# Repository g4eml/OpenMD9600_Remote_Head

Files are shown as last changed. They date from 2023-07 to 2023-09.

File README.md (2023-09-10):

# OpenMD9600_Remote_Head

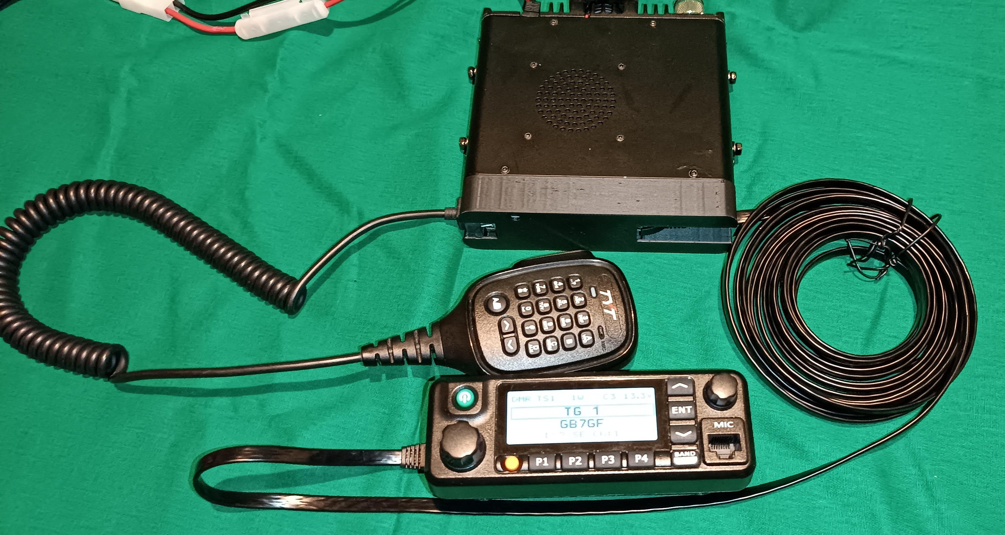
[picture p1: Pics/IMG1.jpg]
MD9600 Remote Head
 

The MD9600 is a good DMR mobile radio but, as standard, it does not have the ability to mount the control head remotely to the main body of the radio. 

The Control Head of the radio is normally connected to the front panel by a 30 conductor Flat Flexible cable. It is impractical to try to extend this cable. 

Now that the radio is able to run the excellent OpenMD9600 firmware it became possible to develop a way of communicating between the radio and the front panel using only a single RJ45 Cat7 cable. This currently requires a modified version of the OpenMD9600 firmware (available from G4EML) but it is hoped that this will be included in a future release of the firmware.  

### <mark>**Note that this modification will only work with the OpenMD9600 firmware. It will not work with the original TYT factory firmware.**</mark>

The mod requres two new small PCBs. 

### Radio Body Interface PCB

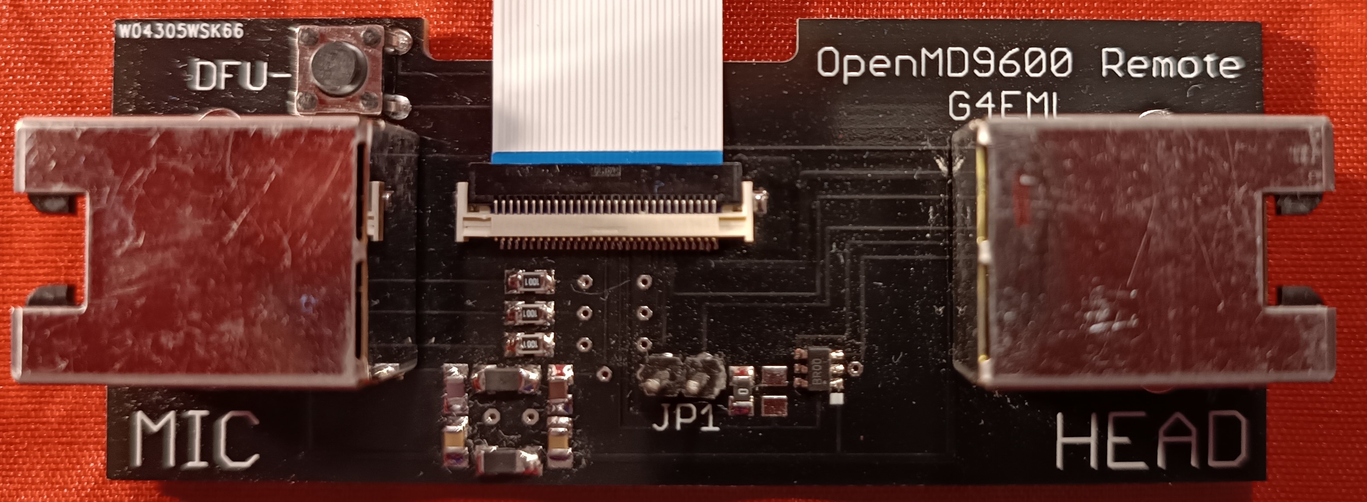
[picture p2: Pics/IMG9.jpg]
BodyPCB


This PCB is fitted to the front of the radio body and is connected to the existing 30 way ribbon cable. The necessary signals are routed to a RJ45 socket. A second RJ45 socket is also provided for direct connection of the microphone to the radio body.  Whilst the microphone can still be connected to the remotely mounted head this can suffer from pickup of noise due to the poor screening of the RJ45 cable. It is therefore recommended to connect the microphone directly to the radio body, using an extension cable if necessary. 

The modifed OpenMD9600 firmware detects the presence of the interface board and reconfigures the existing signals into a suitable format. This is a bi-directional 250000 Baud serial link.  Using this link display data is sent to the remote head PCB and front panel key presses are received from it. 

The PCB includes a digital potentiometer chip which is used to control the radio volume.  This chip is controlled by the remote head PCB.  This is necessary to reduce audio noise pickup on the long cable. Also fitted is a power switch chip which is used to control the power to the microphone. 

### Remote Head Interface PCB

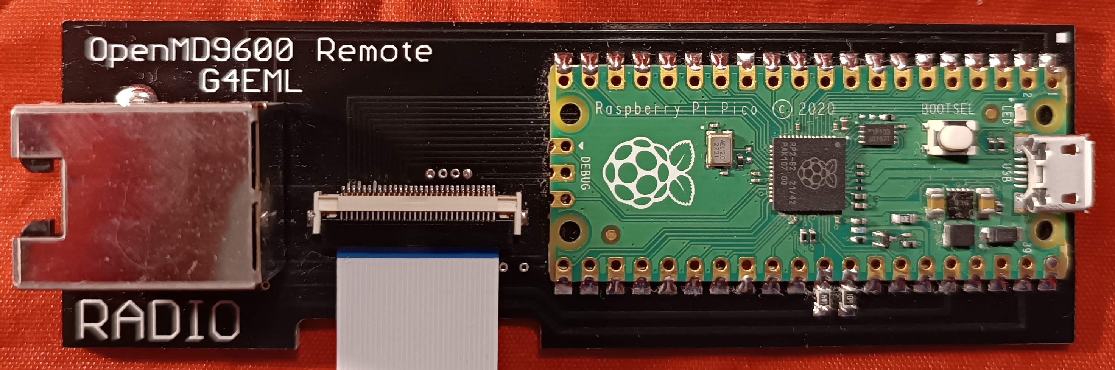
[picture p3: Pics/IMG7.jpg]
Head


This PCB is fitted to the rear of the remote head and connects to the existing 30 way connector.  Serial data to and from the radio body is handled by a Raspberry Pi Pico module which decodes the data and sends it to the Front Panel display, it also reads the front panel buttons and sends their staus to the radio body. 

### Installation

To convert a MD9600 to remote head operation requires the following steps. 

1. Remove front panel from the radio and disconnect the 30 way ribbon cable from the main body. Leave this cable connected to the head.

2. Fit a new 30 way cable between the radio body and the radio body Interface PCB. 

3. Attach the PCB to the front of the radio body using double sided foam tape. 

4. Connect the existing front panel 30 way cable to the remote head interface PCB. 

5. Attach the PCB to the rear of the front panel using double sided foam tape. 

6. Connect the two PCBs togetehr with the RJ45 cable. 

7. Connect the microphone to the second socket on the radio body PCB. 

8. Ensure the MD9600 is running the correct version of OpenMD9600.

9. Power on the radio. It should behave exactly as it did before. 

10. The files are also provided to 3D print covers for the radio body and the head. These are optional but do provide additional protection for the PCBs. 

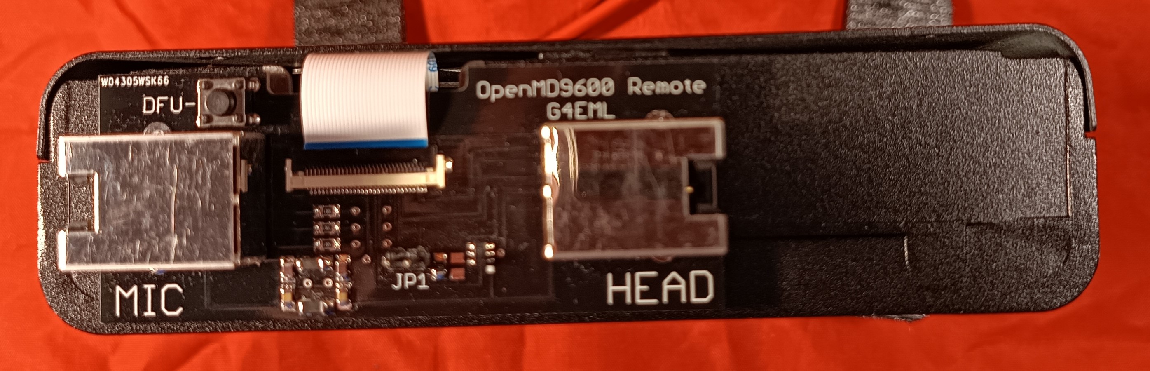
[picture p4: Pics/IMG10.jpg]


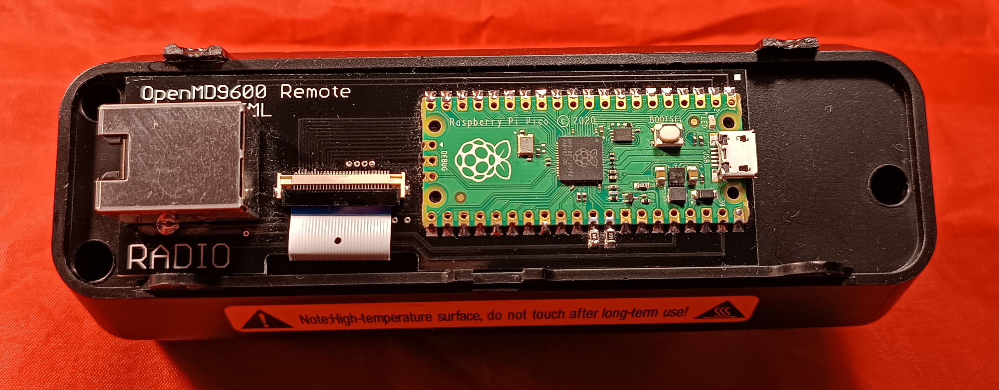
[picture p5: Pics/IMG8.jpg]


### How do I make these boards?

All of the information needed to make your own boards is included in this repository. The gerber files for the PCBs are provided and it is now very easy and cheap to get PCBs made in China. Companies such as PCBWAY will accept the Zipped Gerber files as provided and produce 10 PCBs for about £5.  so that is £10 for 10 of both PCBs. I would suggest that you get together with other people in your country and order the boards. 

The components needed to assemble the boards are easily available and a parts list is provided with Farnell, Mouser and Digikey part numbers. 

The only difficult parts to solder are the ribbon cable connectors and the two SOT23-6 chips. However these can both be done with very carefull hand soldering. 

### Programming the Raspberry Pi Pico (Quick Method)

This can be done either before or after the Pico has been soldered to the PCB, it makes no difference.  

1. Locate the file 'NEW.uf2' which will be found in the Pico Firmware directory of this repository and copy it to your desktop. 

2. Hold down the BOOTSEL button on the Pico while connecting it to your PC using its micro USB port. The Pico should appear as a USB disk drive on your PC.

3. Copy the NEW.uf2 file onto the USB drive. The pico will recognise the file and immediately update its firmware and reboot.

### Programming the Raspberry Pi Pico using the Arduino IDE (longer method).

The Raspberry Pi Pico is programmed using the Arduino IDE with the Earl F. Philhower, III core. 

#### Installing the Arduino IDE

1. Install the Arduino IDE from here https://downloads.arduino.cc/arduino-1.8.19-windows.exe

2. Open the Arduino IDE and go to File/Preferences.

3. in the dialog enter the following URL in the 'Additional Boards Manager URLs' field: https://github.com/earlephilhower/arduino-pico/releases/download/global/package_rp2040_index.json

4. Hit OK to close the Dialog.

5. Go to Tools->Board->Board Manager in the IDE.

6. Type “pico” in the search box and select “Add”:

#### Downloading the Software.

1. Download the zipped software from https://github.com/g4eml/OpenMD9600_Remote_Head/archive/refs/heads/main.zip

2. Save it to a convenient location and then unzip it. 

#### Programming the Pico

1. Open the Arduino IDE and click File/Open

2. Navigate to the File Arduino/MD9600_Remote_Head/MD9600_Remote_Head.ino (downloaded in the previous step) and click Open.

3. Select Tools/ and make the following settings. 
   
   Board: "Raspberry Pi Pico"
   
   Flash Size: "2Mb (no FS)"
   
   CPU Speed: "133MHz"
   
   Optimise: "Small (-Os)(standard)"
   
   RTTI: "Disabled"
   
   Stack Protection: "Disabled"
   
   C++ Exceptions: "Disabled"
   
   Debug Port: "Disabled"
   
   Debug Level: "None"
   
   USB Stack: "Pico SDK"
   
   IP/Bluetooth Stack: "IPv4 Only"
   
   Upload Method: "Default (UF2)"

4. Connect the Rasperry Pi Pico using the USB port. 

5. Click Sketch/Upload.

The Sketch should compile and upload automatically to the Pico. If the upload fials you may need to disconnect the Pico and then hold down the BOOTSEL button while reconnecting. 

If all has gone well the remote head display should light up and display "MD9600 Remote Head'

Disconnect the USB cable, dconnect the head to the radio body with the RJ45 cable and apply power to the radio.

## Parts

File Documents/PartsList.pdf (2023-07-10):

### Sheet1

### Page 1

Description | Quantity | Manufacturer | Part Number | Farnell | Mouser | Digikey
PCB Radio Interface | 1 | PCBWAY
PCB Head Interface | 1 | PCBWAY
Raspberry Pi Pico | 1 | Raspberry Pi | RASPBERRY PI PICO | 3643332 | 358-SC0915
Digital POT 10K SOT23-5 | 1 | Microchip | MCP4013T-103E/CH | 1834923 | 579-MCP4013T-103E/CH | MCP4013T-103E/CHCT-ND
High Side Switch SO23-6 | 1 | Vishay | SIP32510DT-T1-GE3 | 2361514 | 78-SIP32510DT-T1-GE3 | SIP32510DT-T1-GE3CT-ND
FFC Connector 0.5mm Pitch Bottom Contacts 30 way | 2 | Molex | 505110-3091 | 2500024 | 538-505110-3091 | WM11291CT-ND
FFC Cable 50mm | 1 | Wurth | 687630050002 | 1908531 | 710-687630050002 | 732-3569-ND
RJ45 Jack | 3 | Stewart | SS-60000-009 | 1572188 | 530-SS-60000-009 | 380-1096-ND
Tactile Switch 6mm | 1 | C&K | PTS645SL50-2 LFS | 2435162 | 611-PTS645SL502 | CKN9092-ND
Ferrite Bead | 2 | Fair-Rite | 2512067007Y3 | 1653393 | 623-2512067007Y3 | 1934-1490-1-ND
Capacitor 100n 0805 | 2 | MultiComp | MCCA001225 | 1856422
Capacitor 100p 0805 | 2 | MultiComp | MC0805N101J500CT | 1759203
Capacitor 10n 0805 | 2 | MultiComp | MCSH21B103K100CT | 1856414
Resistor 100K 0805 | 2 | MultiComp | MCMR08X104 JTL | 2073613
Resistor 1K 0805 | 3 | MultiComp | MCMR08X102 JTL | 2073611
Resistor 0 Ohm | 1 | MultiComp | MCMR08X000 PTL | 2073603
2 Pin Header | 1 | AMP | 826936-2 | 3133821 | 571-826936-2 | A122912-ND
2Pin Jumper | 1 | AMP | 382811-8 | 2751487 | 571-3828118 | A26228-ND

RJ45 CAT7 Cable

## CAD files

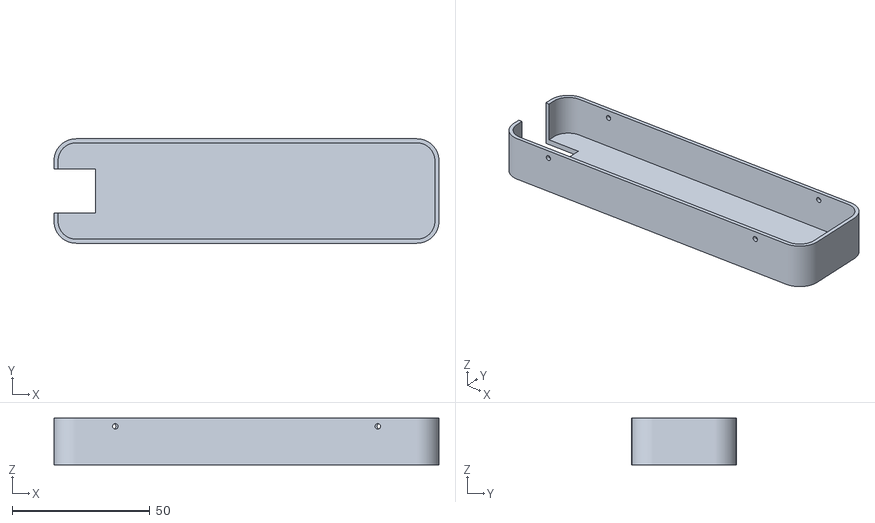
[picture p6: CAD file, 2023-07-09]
3D Printing/Head Cover.stl
140.0 x 38.0 x 17.0

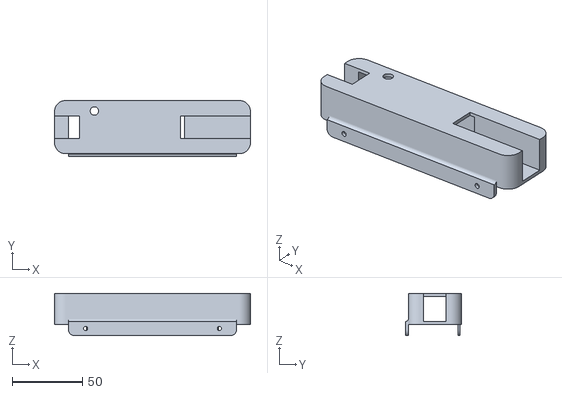
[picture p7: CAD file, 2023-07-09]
3D Printing/Body Cover.stl
140.0 x 40.0 x 30.0

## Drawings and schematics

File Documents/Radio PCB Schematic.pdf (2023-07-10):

## DFU RJ45 Local

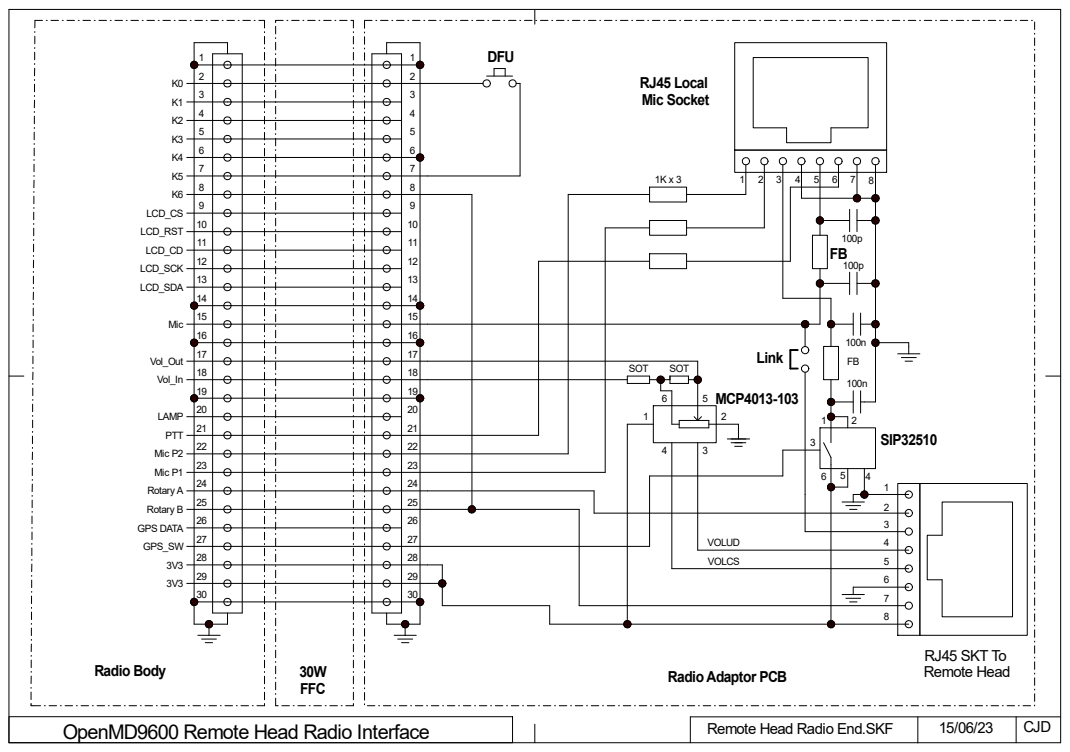
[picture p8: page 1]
LCD_CS; LCD_RST; LCD_CD; LCD_SCK; LCD_SDA; Mic; Vol_Out; Vol_In; LAMP; PTT; Mic P2; Mic P1; Rotary A; Rotary B; GPS DATA; GPS_SW; Radio Body; RJ45 SKT To Remote Head; Remote Head Radio End.SKF; CJD; 30W FFC; Mic Socket; Link; VOLCS; VOLUD; MCP4013-103; SOT; 3 SIP32510

Radio Adaptor PCB

OpenMD9600 Remote Head Radio Interface

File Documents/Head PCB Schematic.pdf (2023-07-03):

## Raspberry Pi Pico

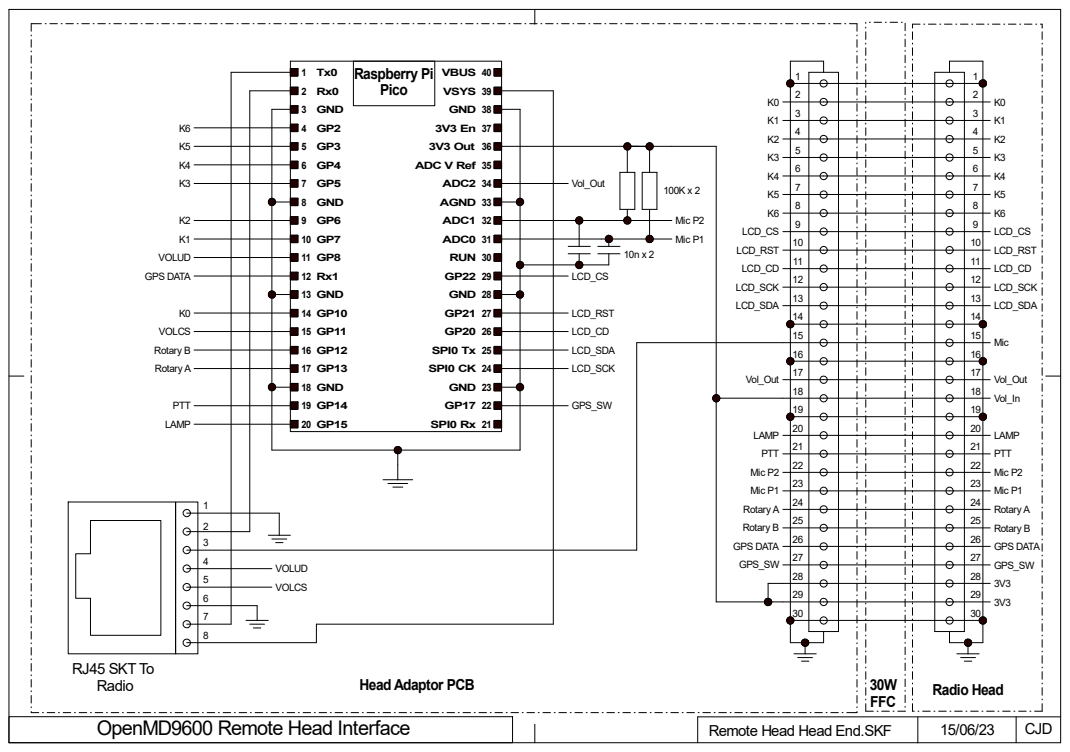
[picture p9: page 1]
LCD_CS 9; LCD_RST 10; LCD_CD 11; LCD_SCK 12; LCD_SDA; Mic 15; Vol_Out 17; Vol_In; LAMP; PTT; Mic P2 22; Mic P1 23; Rotary A; Rotary B; GPS DATA; GPS_SW 27; Radio Head; 30W FFC; OpenMD9600 Remote Head Interface; Remote Head Head End.SKF; CJD; RJ45 SKT To Radio; LCD_CS; LCD_RST; LCD_CD; LCD_SCK; Mic P2; Mic P1; GPS_SW; 3V3 Out; VSYS; GND; AGND; SPI0 Rx; SPI0 CK; SPI0 Tx; ADC1; ADC0; RUN; ADC V Ref; VBUS; VOLUD; VOLCS; ADC2; Vol_Out

Head Adaptor PCB

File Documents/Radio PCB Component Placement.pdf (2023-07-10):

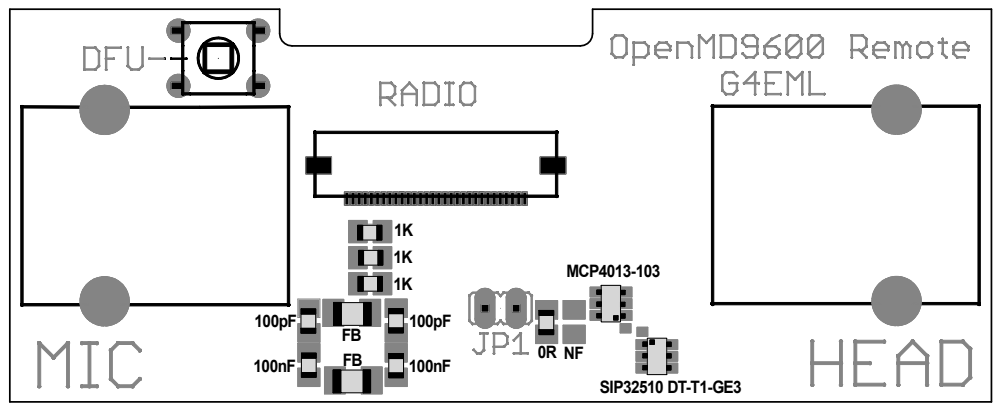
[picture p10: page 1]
MCP4013-103; SIP32510 DT-T1-GE3

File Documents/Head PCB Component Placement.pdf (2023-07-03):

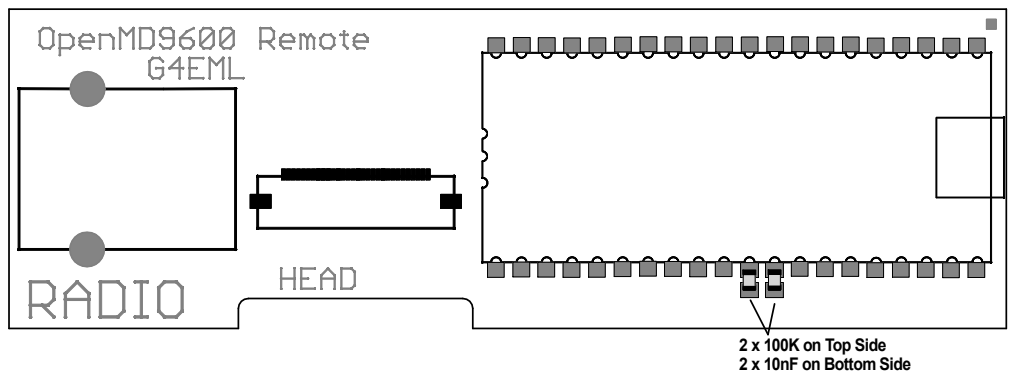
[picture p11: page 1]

2 x 100K on Top Side
2 x 10nF on Bottom Side

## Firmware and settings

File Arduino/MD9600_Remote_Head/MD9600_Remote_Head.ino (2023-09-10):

#include <SPI.h>
#include <EEPROM.h>


#define COM1TX   0      //Pin 1
#define COM1RX   1      //Pin 2
#define COM2TX   8      //Pin 11   (don't need this pin so it is redefined as GPIO for use as VOLUD)
#define COM2RX   9      //Pin 12
#define LAMP 15         //Pin 20
#define MIC_POWER  17   //Pin 22
#define PTT 14          //Pin 19
#define K0 10            //Pin 14
#define K1 7            //Pin 10
#define K2 6            //Pin 9
#define K3 5            //Pin 7
#define K4 4            //Pin 6
#define K5 3            //Pin 5
#define K6 2            //Pin 4
#define ROTARYA 13       //Pin 17
#define ROTARYB 12      //Pin 16
#define MICP2 A0        //Pin 31
#define MICP1 A1        //Pin 32
#define LCDRESET 21     //Pin 27
#define LCDRX  16       //Pin 21      Not used but must be defined.
#define LCDCD  20       //Pin 26
#define LCDCS  22       //Pin 29
#define LCDCK  18       //Pin 24
#define LCDDA  19       //Pin 25   
#define VOLCS  11       //Pin 15
#define VOLUD  8        //Pin 11
#define VOLPOT A2       //Pin 34

unsigned int frontKeys;
int8_t rotaryDirection;
uint8_t micRow;
uint8_t micCol;
uint8_t brightness;
uint8_t micPower;
static uint8_t poweredDown = 0;
int volumePot = 0;
static bool GPSon = 0;
static bool DataReceived;

bool reSend = false;

void setup() 
{
Serial.begin(250000);             //Debug USB port
Serial1.setRX(COM1RX);
Serial1.setTX(COM1TX);
Serial2.setRX(COM2RX);
Serial2.setTX(COM2TX);          //will be reset as a GPIO later. 
Serial1.begin(250000);          //Comms to/from radio
Serial2.begin(9600);            //Comms from GPS if fitted
EEPROM.begin(256);

if(EEPROM.read(0) == 73)              //valid EEPROM data?
{
  poweredDown = EEPROM.read(1);         //restore power status from arbitary location. 
} 

pinMode(LAMP,OUTPUT);
pinMode(MIC_POWER,OUTPUT);
pinMode(K0,INPUT);
pinMode(K1,INPUT);
pinMode(K2,INPUT);
pinMode(K3,INPUT);
pinMode(LCDRESET,OUTPUT);
pinMode(LCDCD,OUTPUT);
pinMode(LCDCS,OUTPUT);

pinMode(VOLCS,OUTPUT);
gpio_set_function(VOLUD, GPIO_FUNC_NULL);           //redefine the unused Serial Port 2 Tx pin as a GPIO. 
pinMode(VOLUD,OUTPUT);

pinMode(PTT,INPUT_PULLUP);
pinMode(K4,INPUT_PULLUP);
pinMode(K5,INPUT_PULLUP);
pinMode(K6,INPUT_PULLUP);
pinMode(ROTARYA,INPUT_PULLUP);
pinMode(ROTARYB,INPUT_PULLUP);

analogWriteFreq(20000);           //This value works well with version 1 radios but not with version 3 or later without modification. 
analogWriteRange(255);

analogWrite(LAMP,0);
digitalWrite(MIC_POWER,LOW);
digitalWrite(K0,HIGH);
digitalWrite(K1,HIGH);
digitalWrite(K2,HIGH);
digitalWrite(K3,HIGH);

digitalWrite(VOLCS, HIGH);
digitalWrite(VOLUD,HIGH);

analogReadResolution(12);
attachInterrupt(digitalPinToInterrupt(ROTARYA), rotaryISR, CHANGE);


SPI.setRX(LCDRX);
SPI.setTX(LCDDA);
SPI.setSCK(LCDCK);
SPI.beginTransaction(SPISettings(8000000,MSBFIRST,SPI_MODE3));
SPI.begin(false);           //Start SPI and manually handle the CS pin

digitalWrite(LCDCS,HIGH);
digitalWrite(LCDCD,HIGH);
digitalWrite(LCDRESET,LOW);
delay(1);
digitalWrite(LCDRESET,HIGH);
delay(5);

brightness=255;
micPower=1;
LCDinit();
LCDClear();
LCDlogo();
LCDtest();

if(poweredDown)
  {
    powerDown();
  } 

while((frontKeys != 0) || (micRow != 5) || (micCol != 4))
{
  readKeys();
  readMicButtons();
}

volPotStep(-64);          //ensure digital pot starts at zero volume. 
 
}

void setup1()
{
  
}

//First Core task is to send to the radio
void loop() 
{
static int lastkeys=0;
static int lastVolume=0;
static uint8_t lastMRow=5;
static uint8_t lastMCol=4;
static uint8_t lastBrightness = 0;
static uint8_t lastMicPower = 0;
static char buff[10];

delay(1);
 if (micPower != lastMicPower)
    {
      digitalWrite(MIC_POWER,micPower);
      lastMicPower=micPower;
    }

  if(brightness != lastBrightness)
    {
    analogWrite(LAMP,brightness);
    lastBrightness=brightness;
    }
    
readKeys();

if(! poweredDown)
  {
    if((frontKeys != lastkeys) || (reSend))
    {
      reSend = false;
      lastkeys=frontKeys;
      Serial1.write('K');
      Serial1.write(frontKeys >> 8);
      Serial1.write(frontKeys & 0xFF);
      Serial.print("Keys ");
      Serial.println(frontKeys,HEX);
    }

  readMicButtons();
  if((micRow != lastMRow) || (micCol != lastMCol))
    {
      lastMRow=micRow;
      lastMCol=micCol;
      Serial1.write('M');
      Serial1.write(micRow);
      Serial1.write(micCol);
      Serial.print("Mic ");
      Serial.println((micRow<<8)+micCol,HEX);
     }
  }
  else
  {
  if(frontKeys == 1)    // Power Button
    {
      poweredDown = false;
      EEPROM.write(0,73);
      EEPROM.write(1,0);
      EEPROM.commit();
      sendBreak();
    }
  }
 

 readVol();
 if((volumePot - lastVolume) != 0)
   {
      volPotStep(volumePot - lastVolume);
      Serial.print(" Vol = ");
      Serial.println(volumePot);
      lastVolume=volumePot;
   }

  if(Serial2.available() > 0)         //received something from the GPS module
    {
      for(int n=Serial2.available();n > 0; n--)
      {
        if(GPSon)
        {
          Serial1.write("G");
          Serial1.write(Serial2.read());
          if(n > 1)
          {
          Serial1.write(Serial2.read());
          n--;  
          }
          else
          {
          Serial1.write((byte)0x00);
          }   
        }
        else
        {
          char dummy=Serial2.read();          //throw away the GPS data
        }
      }
    }
}


//Second core task is to receive from the radio
void loop1()
{
  int ch;
  int bytecount;
  if(Serial1.available() > 1)        //wait till there are at least two characters available
  {
    ch=Serial1.read();
    switch(ch)
    {
      case 'C':
      digitalWrite(LCDCS,LOW);
      digitalWrite(LCDCD,LOW);  // command mode
      ch=Serial1.read();
      LCDtransfer(ch);
      digitalWrite(LCDCS,HIGH);     
      break;

      case 'D':           
      bytecount=Serial1.read();
      digitalWrite(LCDCS,LOW);
      digitalWrite(LCDCD,HIGH);  // data mode
      while(bytecount>0)
      {
       if(Serial1.available()>0)
        {
          ch=Serial1.read();
          LCDtransfer(ch);
          bytecount--; 
        }
      }      
      digitalWrite(LCDCS,HIGH);     
      break;

      case 'B':        //Brightness value
      ch=Serial1.read();
      brightness=ch; 
      break;

      case 'P':         //Mic Power
      ch=Serial1.read();
      micPower = ch & 0x01; 
      break;

      case 'R':         //rescan and resend the keys
      ch=Serial1.read();    //Discard the second byte
      reSend=true; 
      break;

      case 'O':         //Power down
      ch=Serial1.read();    //Discard the second byte
      powerDown();      
      break;
      
      case 'G':         //GPS data on/off
      ch=Serial1.read();
      GPSon = ch & 0x01;
      Serial.print("GPS Data ");
      if(GPSon)
      {
        Serial.println("On");
      }
      else
      {
        Serial.println("Off");
      } 
      break;
    } 
  }
}

void sendBreak(void)
{
  Serial1.end();
  digitalWrite(0,HIGH);
  pinMode(0,OUTPUT);
  digitalWrite(0,LOW);
  delay(100);
  digitalWrite(0,HIGH);
  Serial1.begin(250000);
}

void powerDown(void)
{
  brightness = 0;
  micPower = 0;
  digitalWrite(LCDCS,LOW);
  digitalWrite(LCDCD,LOW);  // command mode

  LCDtransfer(0xAE); // Display Off

  LCDtransfer(0xA5);// All Pixels On

  EEPROM.write(0,73);
  EEPROM.write(1,1);
  EEPROM.commit();
  poweredDown = true;  
}

void rotaryISR(void)
{
  static int lasta=0;
  bool rota=digitalRead(ROTARYA);
  bool rotb=digitalRead(ROTARYB);

if(lasta != rota)
{
   lasta=rota;
    if(rota==rotb)
   {
    rotaryDirection=-1;
   }
   else
   {
    rotaryDirection=1;
   }
}
   
}


void readKeys(void)
{
  frontKeys =0;
  pinMode(K0,OUTPUT);
  digitalWrite(K0,LOW);
  if(digitalRead(K6) == LOW) frontKeys=frontKeys | 0x0001;
  if(digitalRead(K5) == LOW) frontKeys=frontKeys | 0x0002;
  if(digitalRead(K4) == LOW) frontKeys=frontKeys | 0x0004;
  digitalWrite(K0,HIGH);
  pinMode(K0,INPUT);

  pinMode(K1,OUTPUT);
  digitalWrite(K1,LOW);
  if(digitalRead(K6) == LOW) frontKeys=frontKeys | 0x0008;
  if(digitalRead(K5) == LOW) frontKeys=frontKeys | 0x0010;
  if(digitalRead(K4) == LOW) frontKeys=frontKeys | 0x0020;
  digitalWrite(K1,HIGH); 
  pinMode(K1,INPUT);
  
  pinMode(K2,OUTPUT);   
  digitalWrite(K2,LOW);
  if(digitalRead(K6) == LOW) frontKeys=frontKeys | 0x0040;
  if(digitalRead(K5) == LOW) frontKeys=frontKeys | 0x0080;
  if(digitalRead(K4) == LOW) frontKeys=frontKeys | 0x0100;
  digitalWrite(K2,HIGH);
  pinMode(K2,INPUT); 

  pinMode(K3,OUTPUT);     
  digitalWrite(K3,LOW);
  if(digitalRead(K6) == LOW) frontKeys=frontKeys | 0x0200;
  digitalWrite(K3,HIGH);
  pinMode(K3,INPUT); 

  if(digitalRead(PTT)== LOW) frontKeys=frontKeys | 0x8000;

  if(rotaryDirection == 1) frontKeys=frontKeys | 0x4000;
  if(rotaryDirection == -1) frontKeys=frontKeys | 0x2000;
  rotaryDirection = 0;
  
}

void readMicButtons(void)
{
  int rl = 9;
  int cl = 9;

  while((micRow != rl) || (micCol != cl)) 
  {
    rl=micRow;
    cl=micCol;
    micRow = (int)(analogRead(MICP1) / 800);
    micCol = (int)(analogRead(MICP2) / 1000); 
    delay(10);
  }


//prevent half decodes while the row and column are changing. 
  if(micRow > 4) micCol = 4;
  if(micCol >3) micRow=5;
}

void readVol(void)
{
  int ave;
  int total = 0;
  for(ave=0;ave<10;ave++)
  {
  total += analogRead(VOLPOT); 
  }
  volumePot= (total/10) >>6 ;       //convert 12 bit sample to 6 bits. 
}

void volPotStep(int steps)
{
  int s;
  if(steps > 0)       //step up
  {    
    digitalWrite(VOLUD,HIGH);
    delayMicroseconds(1);
    digitalWrite(VOLCS, LOW);
    delayMicroseconds(1);
    digitalWrite(VOLUD, LOW);
    delayMicroseconds(4);
    for(s=steps; s > 0 ; s--)
    {
      digitalWrite(VOLUD, LOW);
      delayMicroseconds(1);
      digitalWrite(VOLUD, HIGH);
      delayMicroseconds(1);   
    }
    digitalWrite(VOLCS, HIGH);
    delay(10);
  }
  else                //step down
  {
    digitalWrite(VOLUD,LOW);
    delayMicroseconds(1);
    digitalWrite(VOLCS, LOW);
    delayMicroseconds(4);
    for(s=steps; s < 0 ; s++)
    {
      digitalWrite(VOLUD, LOW);
      delayMicroseconds(1);
      digitalWrite(VOLUD, HIGH);
      delayMicroseconds(1);;    
    }
    delayMicroseconds(1);
    digitalWrite(VOLCS, HIGH); 
    delay(10);  
  }
}

void LCDinit(void)
{ 
  digitalWrite(LCDCS,LOW);
  digitalWrite(LCDCD,LOW);  // command mode

  LCDtransfer(0xE2); // System Reset

  LCDtransfer(0x2F);// Voltage Follower On
  LCDtransfer(0x81);// Set Electronic Volume = 15
  LCDtransfer(0x12); // Contrast
  LCDtransfer(0xA2); // Set Bias = 1/9
  LCDtransfer(0xA1); // SEG Direction
  LCDtransfer(0xC0); // COM Direction
  LCDtransfer(0xA6); // White background, black pixels
  LCDtransfer(0xAF); // enable

  digitalWrite(LCDCS,HIGH);
}


void LCDtransfer(uint8_t data1)
{
  SPI.transfer(&data1, 1);
}

void LCDClear(void)
{
  digitalWrite(LCDCS,LOW);

  for(int row=0;row<(64/8);row++)
  {
    digitalWrite(LCDCD,LOW);  // command mode
    LCDtransfer(0xB0 | row);        //Start Row
    LCDtransfer(0x10);        //Set X High Byte
    LCDtransfer(0x04);        //4 pixels from the left
    digitalWrite(LCDCD,HIGH);  // data mode
    for(int i=0;i<128 ;i++)
      {
        LCDtransfer(0x00);        //8 vertical bits of data
      }
  }
  digitalWrite(LCDCS,HIGH);
}

void LCDlogo(void)
{
  uint8_t logo[] = {
                    0x00,0x00,0x00,0x00,0x00,0x00,0x00,0x00,0x00,0x00,
                    0x7f, 0x02, 0x0c, 0x02, 0x7f, 0x00,0x7f, 0x41, 0x41, 0x22, 0x1c, 0x00,0x06, 0x49, 0x49, 0x29, 0x1e, 0x00,0x3c, 0x4a, 0x49, 0x49, 0x30, 0x00,0x3e, 0x51, 0x49, 0x45, 0x3e, 0x00,0x3e, 0x51, 0x49, 0x45, 0x3e, 0x00,
                    0x00, 0x00, 0x00, 0x00, 0x00, 0x00,0x7f, 0x09, 0x19, 0x29, 0x46, 0x00,0x38, 0x54, 0x54, 0x54, 0x18, 0x00,0x7c, 0x04, 0x18, 0x04, 0x78, 0x00,0x38, 0x44, 0x44, 0x44, 0x38, 0x00,0x04, 0x3f, 0x44, 0x40, 0x20, 0x00,
                    0x38, 0x54, 0x54, 0x54, 0x18, 0x00,0x00, 0x00, 0x00, 0x00, 0x00, 0x00,0x7f, 0x08, 0x08, 0x08, 0x7f, 0x00,0x38, 0x54, 0x54, 0x54, 0x18, 0x00,0x20, 0x54, 0x54, 0x54, 0x78, 0x00,0x38, 0x44, 0x44, 0x48, 0x7f, 0x00,
                    0x00,0x00,0x00,0x00,0x00,0x00,0x00,0x00,0x00,0x00
                    };
  digitalWrite(LCDCS,LOW);

    digitalWrite(LCDCD,LOW);  // command mode
    LCDtransfer(0xB4);        //Start Row
    LCDtransfer(0x10);        //Set X High Byte
    LCDtransfer(0x04);        //4 pixels from the left
    digitalWrite(LCDCD,HIGH);  // data mode
    for(int i=0;i<128 ;i++)
      {
        LCDtransfer(logo[i]);        //8 vertical bits of data
      }
    digitalWrite(LCDCS,HIGH);
}

void LCDtest(void)
{
    digitalWrite(LCDCS,LOW);
    digitalWrite(LCDCD,LOW);  // command mode
    LCDtransfer(0xB7);        //Start Row
    LCDtransfer(0x10);        //Set X High Byte
    LCDtransfer(0x04);        //4 pixels from the left
    digitalWrite(LCDCD,HIGH);  // data mode
    digitalWrite(LCDCS,HIGH);
}

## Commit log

2023-07-09 Add 3D printed Covers
    [Body Cover.stl, Head Cover.stl, Partslist.ods]
2023-07-10 Update PCBs
    [MD9600 Radio.brd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]
2023-07-10 Update Docs
    [Partslist.ods]
2023-09-10 Fix multiple front panel key presses.
    [MD9600_Remote_Head.ino]
